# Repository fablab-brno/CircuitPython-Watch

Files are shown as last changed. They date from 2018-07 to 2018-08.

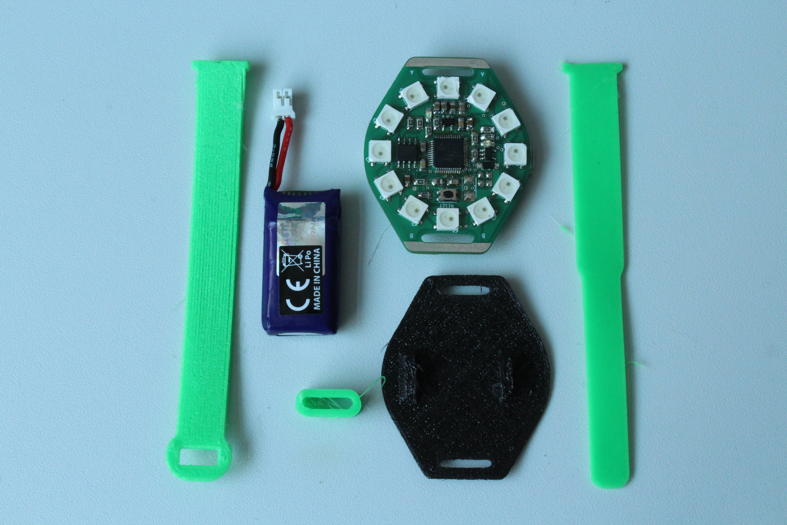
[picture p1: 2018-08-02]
HW/images/IMG_3321.JPG

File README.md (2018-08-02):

# CircuitPython Watch

This is sort of CircuitPlayground Express clone with Neopixel ring and RTC DS3231.

Goal of this board is make real working watch for Maker Faire Prague (MFP) which can children age of 10+ years make at workshop and which can after that use to learn Circuitpython.   

Sadly we encountered some issues at MFP with assembly of the board, so just 2 watches were made. 

Until now, there were 2 revisions of the board: 

version A: 
- I2C was routed to wrong pins
- VCC was split in 2 signals in schematic so I have to connect them at board with wire
- VBAT was connected to 5V so if I tryed to charge battery there was to much voltage and battery did not charge
- it has not SWDIO & SWCLK pins so I had to solder wires to the pins of the CPU to burn the bootloader
	
version B:
- board is working & ready for MFP
	
Description of the board:
- uses ATSAMD21G18 like CPX
- uses AP131 voltage regulator (5V -> 3.3V)
- uses MCP73831 for battery charging
- uses DS3231 for RTC
- uses UF2 bootloader
- uses micro USB connector for charging & data transfer
- uses 12 WS2812B RGB diodes to schow time
	
Description of usage:

There are 2 touch buttons on the board. 

Button A is "Time button", when is pressed, it will show hours by blue color on RGB LEDs and minutes by green color. Every minute is schowed by 1 blink of green color. 

Button B is  "Mode button", when is pressed, it will increase counter by 1 and it will schow predefined animation from main.py .

Function is showed in gif bellow, in loop with all default animations. 
<p>
<a href="https://imgflip.com/gif/2f5eqi">made at imgflip.com</a>
</p>

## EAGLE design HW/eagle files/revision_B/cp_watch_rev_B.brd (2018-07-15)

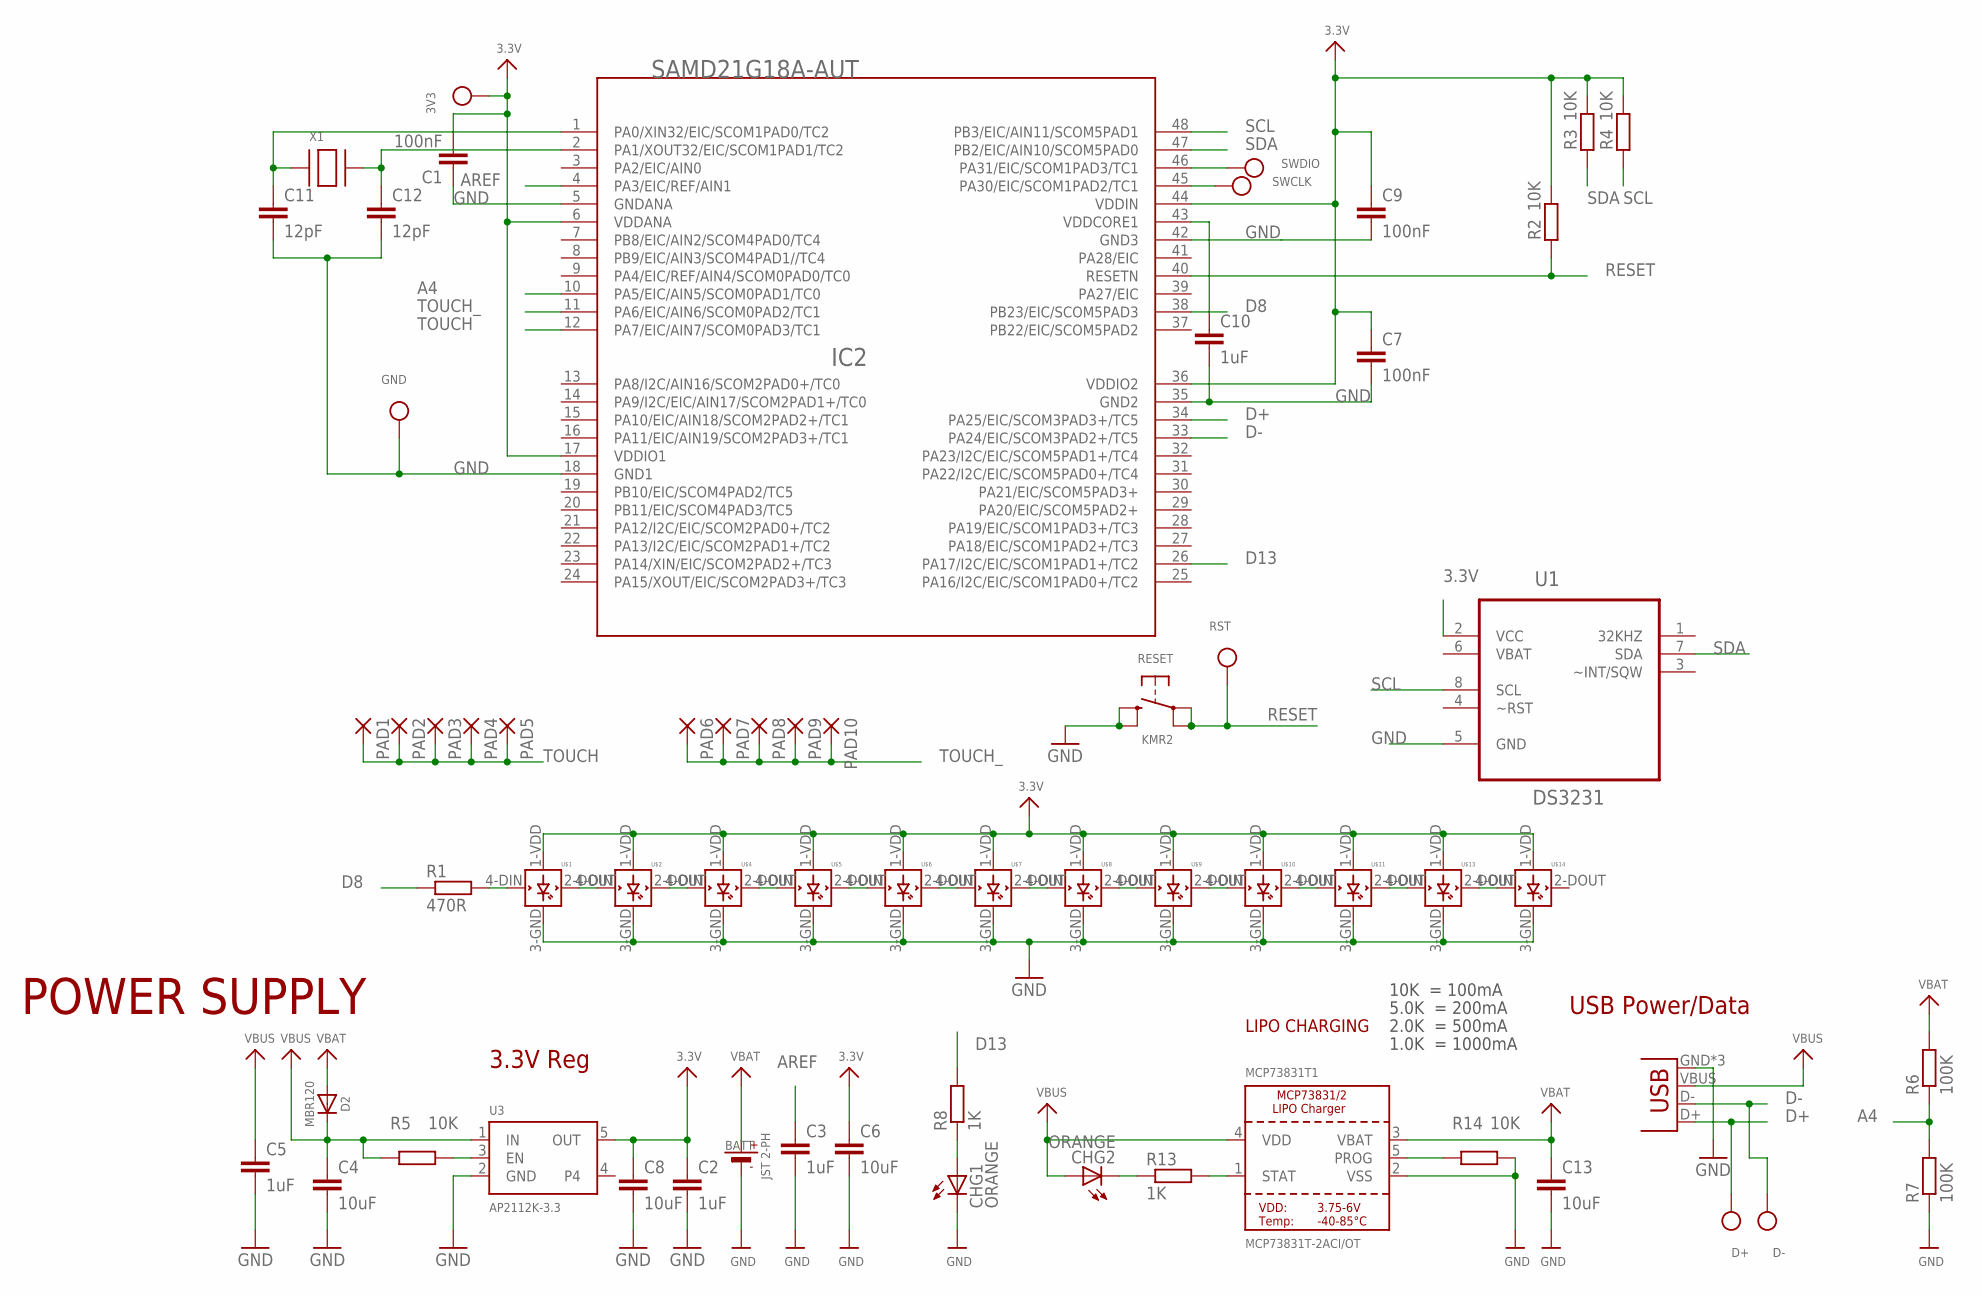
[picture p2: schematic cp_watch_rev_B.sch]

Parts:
3V3: TESTPOINTROUND1MM; TESTPOINT_ROUND_1MM
BATT: JST 2-PH; JSTPH2
C1, C7, C9: 100nF; C0805
C2, C3, C5, C10: 1uF; C0805
C4, C6, C8, C13: 10uF; C0805
C11, C12: 12pF; C0805
CHG1, CHG2: ORANGE; CHIPLED_0805
D2: MBR120; SOD-123
D+: TESTPOINTROUND1MM; TESTPOINT_ROUND_1MM
D-: TESTPOINTROUND1MM; TESTPOINT_ROUND_1MM
GND: TESTPOINTROUND1MM; TESTPOINT_ROUND_1MM
IC2: SAMD21G18A-AUT; TQFP48
MCP73831T1: MCP73831T-2ACI/OT; SOT23-5
PAD1, PAD2, PAD3, PAD4, PAD5, PAD6, PAD7, PAD8, PAD9, PAD10: SMD5; SMD2,54-5,08
R1: 470R; R0805
R2, R3, R4, R5, R14: 10K; R0805
R6, R7: 100K; R0805
R8, R13: 1K; R0805
RESET: KMR2; BTN_KMR2_4.6X2.8
RST: TESTPOINTROUND1MM; TESTPOINT_ROUND_1MM
SWCLK: TESTPOINTROUND1MM; TESTPOINT_ROUND_1MM
SWDIO: TESTPOINTROUND1MM; TESTPOINT_ROUND_1MM
U1: DS3231; SOIC8_150MIL
U3: AP2112K-3.3; SOT95P290X120-5
U$1, U$2, U$4, U$5, U$6, U$7, U$8, U$9, U$10, U$11, U$13, U$14: WS2812B
USB: USB_MICRO_ATTEND_; USB_MICRO
X1: XTALNX5032; NX5032

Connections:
3.3V: 3V3.P$1, C1.2, C2.1, C6.1, C7.1, C8.1, C9.1, IC2.6 (VDDANA), IC2.17 (VDDIO1), IC2.36 (VDDIO2), IC2.44 (VDDIN), R2.2, R3.2, R4.2, U1.2 (VCC), U3.5 (OUT), U$1.1-VDD (VDD), U$2.1-VDD (VDD), U$4.1-VDD (VDD), U$5.1-VDD (VDD), U$6.1-VDD (VDD), U$7.1-VDD (VDD), U$8.1-VDD (VDD), U$9.1-VDD (VDD), U$10.1-VDD (VDD), U$11.1-VDD (VDD), U$13.1-VDD (VDD), U$14.1-VDD (VDD)
A4: IC2.10 (PA5/EIC/AIN5/SCOM0PAD1/TC0), R6.1, R7.2
AREF: C3.1, IC2.4 (PA3/EIC/REF/AIN1)
D8: IC2.38 (PB23/EIC/SCOM5PAD3), R1.1
D13: IC2.26 (PA17/I2C/EIC/SCOM1PAD1+/TC2), R8.2
D+: D+.P$1, IC2.34 (PA25/EIC/SCOM3PAD3+/TC5), USB.D+
D-: D-.P$1, IC2.33 (PA24/EIC/SCOM3PAD2+/TC5), USB.D-
GND: BATT.1 (-), C1.1, C2.2, C3.2, C4.2, C5.2, C6.2, C7.2, C8.2, C9.2, C10.2, C11.2, C12.2, C13.2, CHG1.C, GND.P$1, IC2.5 (GNDANA), IC2.18 (GND1), IC2.35 (GND2), IC2.42 (GND3), MCP73831T1.2 (VSS), R7.1, R14.2, RESET.B (S), RESET.B' (S1), U1.5 (GND), U3.2 (GND), U$1.3-GND (GND), U$2.3-GND (GND), U$4.3-GND (GND), U$5.3-GND (GND), U$6.3-GND (GND), U$7.3-GND (GND), U$8.3-GND (GND), U$9.3-GND (GND), U$10.3-GND (GND), U$11.3-GND (GND), U$13.3-GND (GND), U$14.3-GND (GND), USB.GND, USB.GND@2 (GND), USB.GND@3 (GND)
unnamed: C11.1, IC2.1 (PA0/XIN32/EIC/SCOM1PAD0/TC2), X1.P$1
unnamed: IC2.45 (PA30/EIC/SCOM1PAD2/TC1), SWCLK.P$1
unnamed: R5.2, U3.3 (EN)
unnamed: R1.2, U$1.4-DIN (DIN)
unnamed: C10.1, IC2.43 (VDDCORE1)
unnamed: U$1.2-DOUT (DOUT), U$2.4-DIN (DIN)
unnamed: C12.1, IC2.2 (PA1/XOUT32/EIC/SCOM1PAD1/TC2), X1.P$2
unnamed: U$2.2-DOUT (DOUT), U$4.4-DIN (DIN)
unnamed: U$4.2-DOUT (DOUT), U$5.4-DIN (DIN)
unnamed: U$5.2-DOUT (DOUT), U$6.4-DIN (DIN)
unnamed: U$6.2-DOUT (DOUT), U$7.4-DIN (DIN)
unnamed: U$7.2-DOUT (DOUT), U$8.4-DIN (DIN)
unnamed: U$8.2-DOUT (DOUT), U$9.4-DIN (DIN)
unnamed: U$9.2-DOUT (DOUT), U$10.4-DIN (DIN)
unnamed: U$10.2-DOUT (DOUT), U$11.4-DIN (DIN)
unnamed: U$11.2-DOUT (DOUT), U$13.4-DIN (DIN)
unnamed: U$13.2-DOUT (DOUT), U$14.4-DIN (DIN)
unnamed: CHG1.A, R8.1
unnamed: CHG2.C, R13.1
unnamed: MCP73831T1.1 (STAT), R13.2
unnamed: MCP73831T1.5 (PROG), R14.1
RESET: IC2.40 (RESETN), R2.1, RESET.A, RESET.A' (P1), RST.P$1
SCL: IC2.48 (PB3/EIC/AIN11/SCOM5PAD1), R4.1, U1.8 (SCL)
SDA: IC2.47 (PB2/EIC/AIN10/SCOM5PAD0), R3.1, U1.7 (SDA)
SWDIO: IC2.46 (PA31/EIC/SCOM1PAD3/TC1), SWDIO.P$1
TOUCH: IC2.12 (PA7/EIC/AIN7/SCOM0PAD3/TC1), PAD1.1, PAD2.1, PAD3.1, PAD4.1, PAD5.1
TOUCH_: IC2.11 (PA6/EIC/AIN6/SCOM0PAD2/TC1), PAD6.1, PAD7.1, PAD8.1, PAD9.1, PAD10.1
VBAT: BATT.2 (+), C13.1, D2.A, MCP73831T1.3 (VBAT), R6.2, U1.6 (VBAT)
VBUS: C4.1, C5.1, CHG2.A, D2.C, MCP73831T1.4 (VDD), R5.1, U3.1 (IN), USB.VBUS

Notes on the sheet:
USB Power/Data
3.3V Reg
POWER SUPPLY
10K = 100mA
5.0K = 200mA
2.0K = 500mA
1.0K = 1000mA
LIPO CHARGING

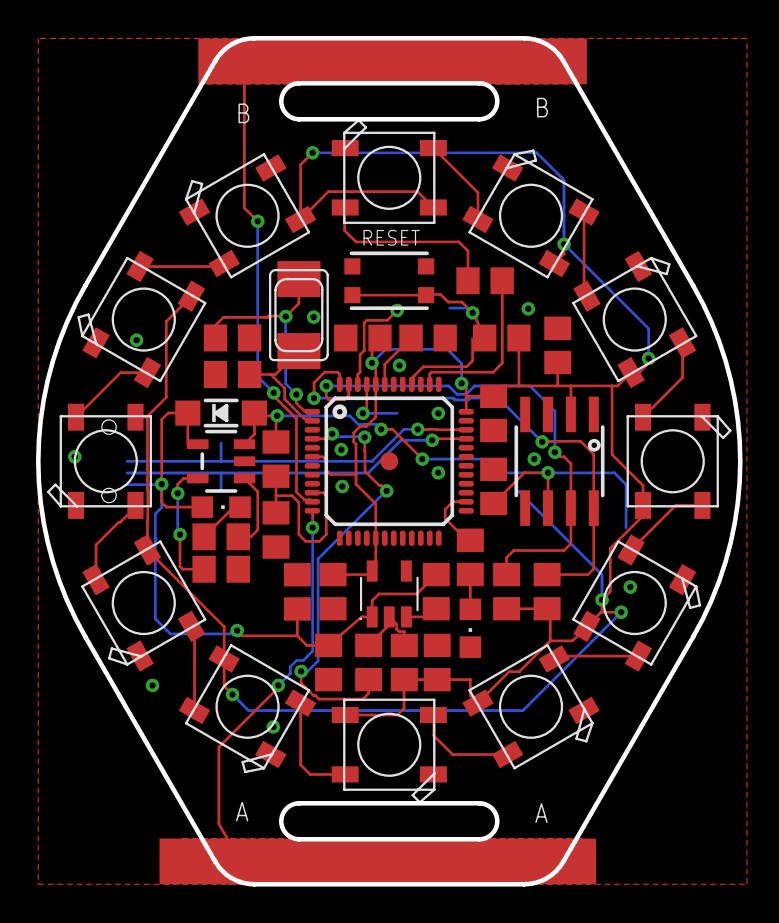
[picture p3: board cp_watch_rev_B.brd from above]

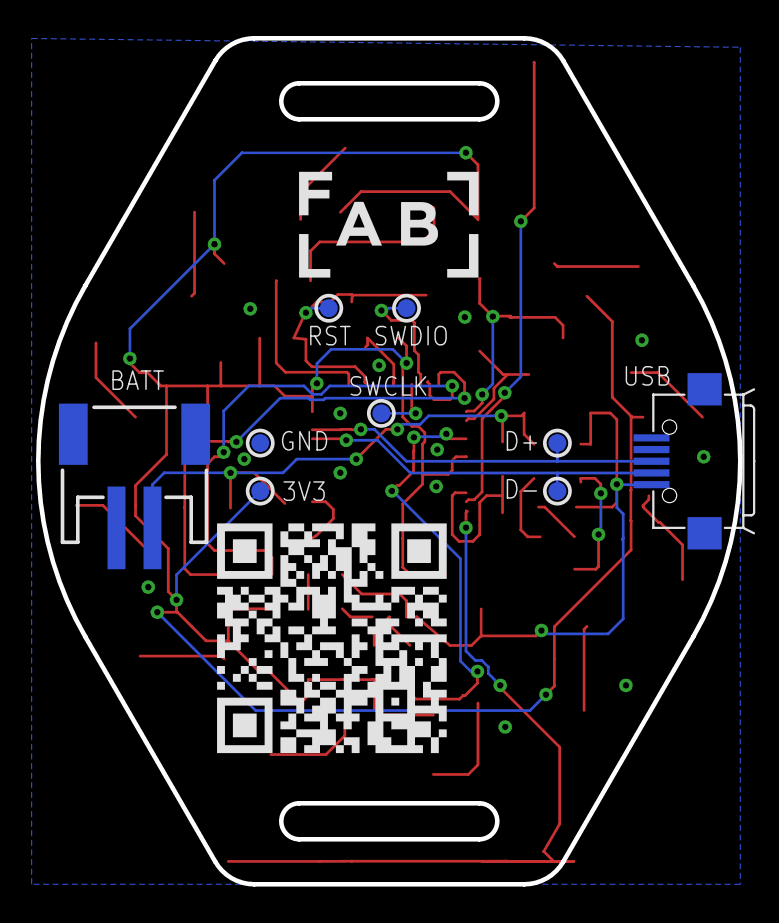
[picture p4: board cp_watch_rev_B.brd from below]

Board: 2 copper layers, 39.0 x 47.0 mm, 63 parts (9 on the bottom side), 37 nets.

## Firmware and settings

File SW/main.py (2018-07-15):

# FabLab CircuitPython Watch

# pripojeni pouzitych knihoven
import time
import board
import busio as io
import adafruit_ds3231
from analogio import AnalogIn
import touchio
import digitalio
import neopixel

# Nastaveni cisla analogoveho pinu pro cteni napeti baterie
analog_in = AnalogIn(board.A1)

# Nastaveni cisel pinu s dotykovymi tlacitky
touch_pad_A = board.A3
touch_pad_B = board.A2

# Nastaveni tlacitek jako objektu z knihovny touchio
touchA = touchio.TouchIn(touch_pad_A)
touchB = touchio.TouchIn(touch_pad_B)

# Vytvoreni LED diody na pinu D13 a nastaveni jako vystupu
led = digitalio.DigitalInOut(board.D13)
led.direction = digitalio.Direction.OUTPUT

# 12 NeoPixel LED diod) pripojenych na pin D8
NUMPIXELS = 12
pixels = neopixel.NeoPixel(board.D8, NUMPIXELS, brightness=0.1, auto_write=False)

# Vytvoreni I2C instance
i2c = io.I2C(board.SCL, board.SDA)
# Vytvoreni RTC instance
rtc = adafruit_ds3231.DS3231(i2c)

# Barevny mod
barevny_mod = 0
animace_pred_casem = 0
animace_po_casu = 1

if False:   # Pro nastaveni casu zmente podminku na "if True"
    #                      rok, mesic, den, hod, min, sek, wday, yday, isdst
    t = time.struct_time((2018,  06,   20,   22,  46,  55,    0,   -1,    -1))
    print("Cas nastaven na:", t)
    rtc.datetime = t

################### Definice podprogramu ###############
def wheel(pos):
    # Input a value 0 to 255 to get a color value.
    # The colours are a transition r - g - b - back to r.
    if pos < 85:
        return (int(pos * 3), int(255 - (pos * 3)), 0)
    elif pos < 170:
        pos -= 85
        return (int(255 - (pos * 3)), 0, int(pos * 3))
    else:
        pos -= 170
        return (0, int(pos * 3), int(255 - pos * 3))

def rainbow_cycle(wait):
    for j in range(0, 255, 2):
        for i in range(len(pixels)):
            idx = int((i * 256 / len(pixels)) + j * 10)
            pixels[i] = wheel(idx & 255)
        pixels.show()
        time.sleep(wait)

def rainbow(wait):
    for j in range(0, 255, 2):
        for i in range(len(pixels)):
            idx = int(i + j)
            pixels[i] = wheel(idx & 255)
        pixels.show()
        time.sleep(wait)

def simpleCircle(wait):
    RED = ((255, 0, 0))
    GREEN = ((0, 255, 0))
    BLUE = ((0, 0, 255))

    for i in range(len(pixels)):
        pixels[i] = RED
        pixels.show()
        time.sleep(wait)
    time.sleep(0.4)

    for i in range(len(pixels)):
        pixels[i] = GREEN
        pixels.show()
        time.sleep(wait)
    time.sleep(0.4)

    for i in range(len(pixels)):
        pixels[i] = BLUE
        pixels.show()
        time.sleep(wait)
    time.sleep(0.4)

def neopixels_clear():
    for p in range(NUMPIXELS):
        pixels[p] = ((0,0,0))
        pixels.show()

# Ziskani napeti z analogoveho pinu
def get_voltage(pin):
    # vraceni hodnoty *2, protoze napeti z baterie je odporovym delicem polovicni
    return (pin.value * 3.33 * 2) / 65536

# Vytvoreni barevneho efektu
def barevny_efekt(cislo):
    if (cislo == 0):
        print('Simple demo')
        pixels[0] = ((150,0,0))
        pixels[3] = ((0,150,0))
        pixels[6] = ((0,0,150))
        pixels[9] = ((150,150,150))
        pixels.show()
        time.sleep(1)
        neopixels_clear()
    if (cislo == 1):
        print('Simple Circle Demo')
        simpleCircle(.01)
        neopixels_clear()
    if (cislo == 2):
        print('Flash Demo')
        pixels.fill((255, 0, 0))
        pixels.show()
        time.sleep(.25)

        pixels.fill((0, 255, 0))
        pixels.show()
        time.sleep(.25)

        pixels.fill((0, 0, 255))
        pixels.show()
        time.sleep(.25)

        pixels.fill((255, 255, 255))
        pixels.show()
        time.sleep(.25)
        neopixels_clear()
    if (cislo == 3):
        print('Rainbow Demo')
        rainbow(.001)
        neopixels_clear()
    if (cislo == 4):
        print('Rainbow Cycle Demo')
        rainbow_cycle(.001)
        neopixels_clear()

########################################################
# Nekonecna smycka
while True:
    # Pri stisku tlacitka A provedeme nasledujici:
    if touchA.value:
        #print("Stisknuto tlacitko A!")
        # Provedeni nastavene animace
        if (animace_pred_casem):
            barevny_efekt(barevny_mod)
        # Nacteni casu do promenne
        t = rtc.datetime
        print("Aktualni cas je {}:{:02}:{:02}".format(t.tm_hour, t.tm_min, t.tm_sec))
        # Hodiny
        # Nacteni poctu hodin po zbytku deleni 12 - cas ma 24h format
        hodiny = t.tm_hour%12;
        # Postupne rozsviceni LEDky s udanou hodinou, modra barva
        for p in range(0, 255, 5):
            pixels[hodiny] = ((0,0,p))
            pixels.show()
        # Pauza po dobu 1 sekundy
        time.sleep(1)
        # Postupne zhasnuti LEDky s udanou hodinou, modra barva
        for p in range(255, 0, -5):
            pixels[hodiny] = ((0,0,p))
            pixels.show()
        # Pauza po dobu 400ms
        time.sleep(0.4)
        # Minuty
        # Nacteni poctu minut do promenne
        minuty = t.tm_min;
        # Nacteni cisla minutoveho policka pomoci deleni 5
        minutyPolicko = int(minuty/5);
        # Postupne rozsviceni LEDky s udanou hodinou, zelena barva
        for p in range(0, 255, 5):
            pixels[minutyPolicko] = ((0,p,0))
            pixels.show()
        # Pauza pred dalsim vykonavanim
        time.sleep(0.4)
        # Bliknuti polickem dle poctu minut
        if (minuty-(minutyPolicko*5) > 0):
            # Bliknuti LED diodou
            pixels[minutyPolicko] = ((0,0,0))
            pixels.show()
            time.sleep(0.4)
            pixels[minutyPolicko] = ((0,255,0))
            pixels.show()
            time.sleep(0.4)
            # Pripadne bliknuti zbytku minut
            for p in range(0, (minuty-(minutyPolicko*5)-1), 1):
                pixels[minutyPolicko] = ((0,0,0))
                pixels.show()
                time.sleep(0.4)
                pixels[minutyPolicko] = ((0,255,0))
                pixels.show()
                time.sleep(0.4)
        # Pokud je pocet minut presne dle policka,
        # rovnou provedeme zhasnuti LED diody
        time.sleep(0.6)
        for p in range(255, 0, -5):
            pixels[minutyPolicko] = ((0,p,0))
            pixels.show()
        # Provedeni nastavene animace
        if (animace_po_casu):
            barevny_efekt(barevny_mod)

    # Pri stisku tlacitka B provedeme nasledujici:
    if touchB.value:
        #print("Stisknuto tlacitko B!")
        barevny_mod += 1
        if (barevny_mod > 4):
            barevny_mod = 0
        barevny_efekt(barevny_mod)
        time.sleep(0.5)

    # Nacteni napeti na baterii
    napeti = get_voltage(analog_in)
    # Kontrola nizkeho napeti na baterii
    if (napeti < 3.6):
        # Bliknuti cervenou LED diodou pro vystrahu
        led.value = True
        time.sleep(1)
        led.value = False
        time.sleep(1)
        print("Baterie ma {} V".format(napeti))
    # Pauza 500ms pred dalsim zavolami while True
    time.sleep(0.5)

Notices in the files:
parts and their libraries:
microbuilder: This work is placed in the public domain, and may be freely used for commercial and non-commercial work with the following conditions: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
